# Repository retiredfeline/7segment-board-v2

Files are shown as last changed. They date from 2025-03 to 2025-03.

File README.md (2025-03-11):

# 7 segment 2 digit board

These are the design files for a 7 segment board similar to [6 segment 2 digit board](https://hackaday.io/project/175397-6-segment-2-digit-led-board).

This is a multiplexed design with 7 cathode segment drive lines plus 1 colon line. The cathode drive lines are taken low to turn on the LEDs, while the anode drive lines are taken low to turn on the transistors.

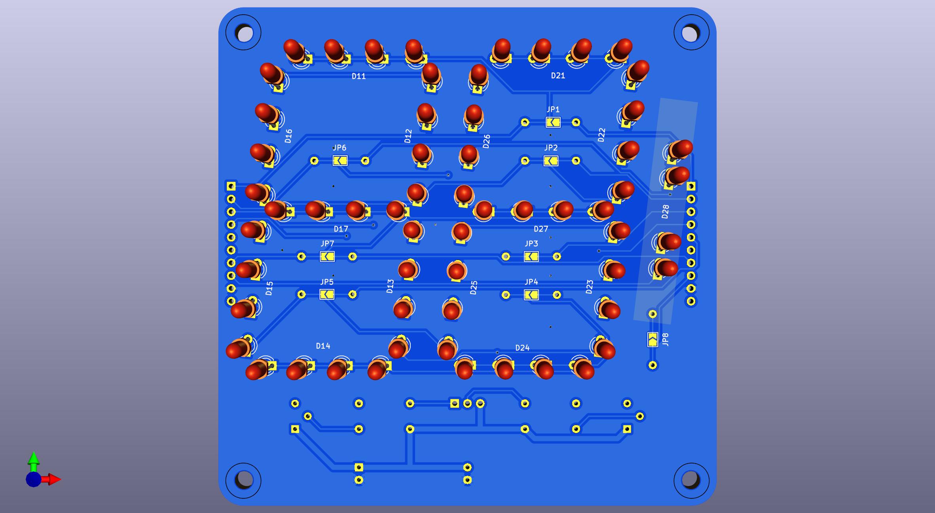
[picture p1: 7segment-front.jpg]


## Versioning

Release March 2025

## Notes

Most components are installed on the back side and the LEDs are installed on the front side.

The PNP transistors need a gain > 40. A bit more margin is recommended.

Note the the LED supply voltage will need to be higher than 4x the LED drop and the cathode current limiting resistor should be calculated accordingly. So 5V will not be sufficient and also a buffer stage will be needed for most MCUs. For example with a 12V supply and green (not emerald) LEDs, the voltage drop per LED is 2V. The transistor drops will be around 0.8V. That leaves 2.2V to be dropped across the resistor. A 220Ω resistor gives 10mA through the LED. For 4 digits multiplexed this is effectively 2.5mA. Modern LEDs are efficient enough to shine brightly at such currents. For dimming, use PWM.

When cascading only the rightmost board needs to be fully populated. The others need only the LEDs, the anode driver transistors, and its resistors. The cathode resistors are not installed and the solder jumpers are closed.

## Authors

* **Ken Yap**

## License

See the [LICENSE](LICENSE.md) file for license rights and limitations (MIT).

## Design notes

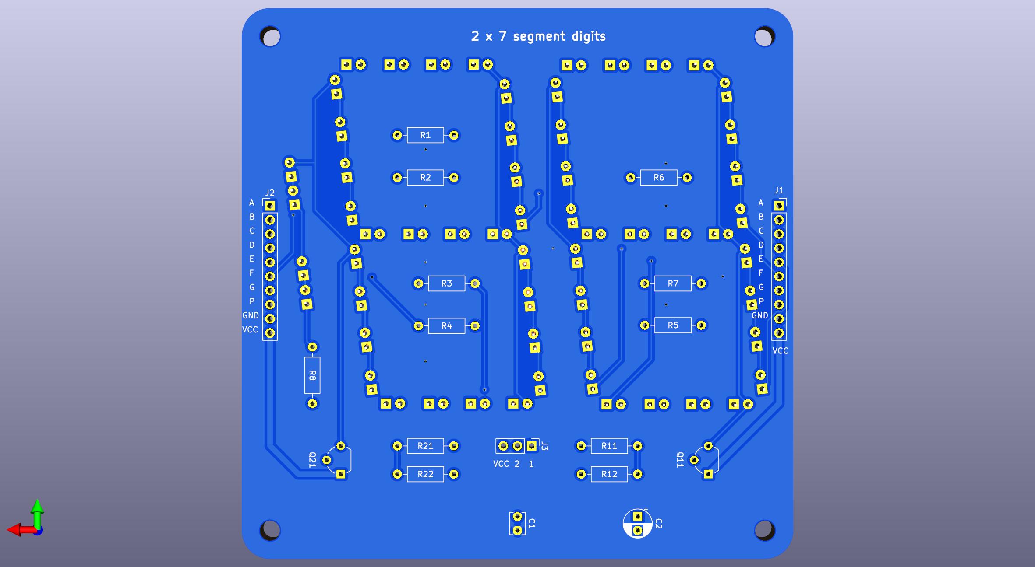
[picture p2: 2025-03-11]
7segment-back.jpg

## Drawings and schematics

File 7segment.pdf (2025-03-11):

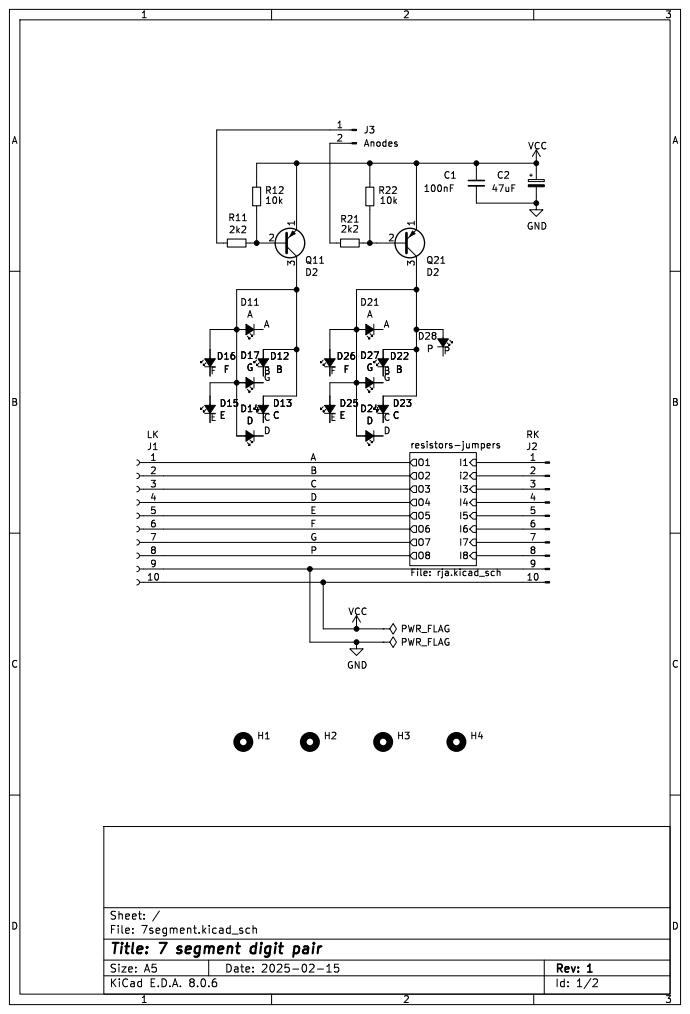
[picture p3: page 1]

Id: 1/2 Title: 7 segment digit pair File: 7segment.kicad_sch Sheet: /

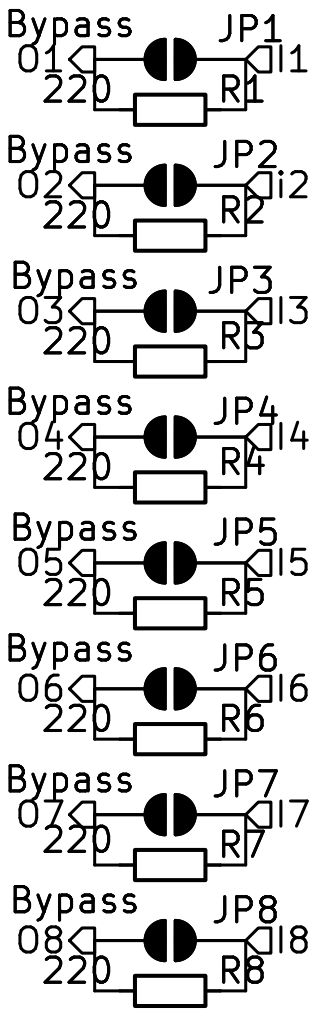
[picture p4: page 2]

File: rja.kicad_sch Sheet: /resistors-jumpers/
Id: 2/2 Title: Resistor jumper array

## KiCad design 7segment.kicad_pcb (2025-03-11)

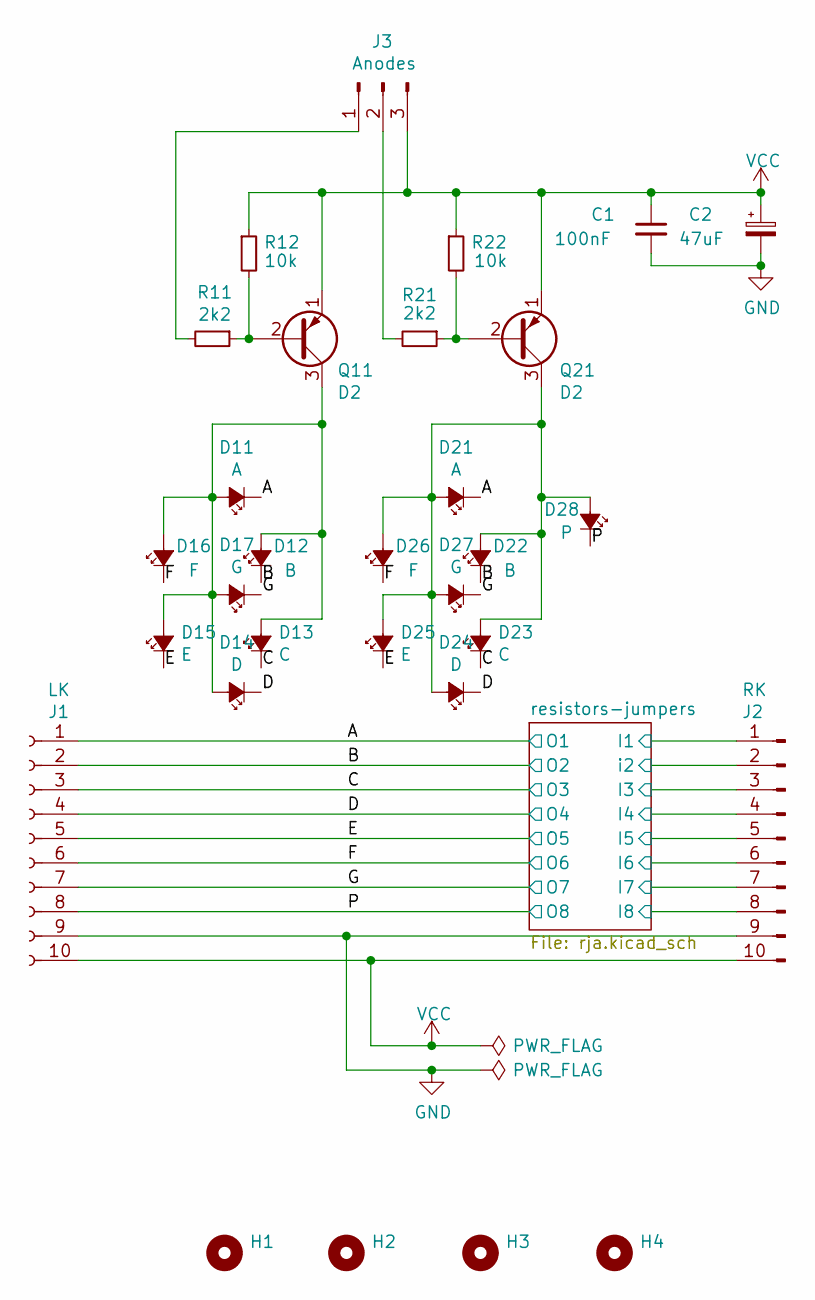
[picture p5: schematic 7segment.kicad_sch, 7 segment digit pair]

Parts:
C1: 100nF; C_Disc_D3.8mm_W2.6mm_P2.50mm
C2: 47uF; CP_Radial_D5.0mm_P2.50mm
D11, D21: A; LED_D3.0mmx4
D12, D22: B; LED_D3.0mmx4
D13, D23: C; LED_D3.0mmx4
D14, D24: D; LED_D3.0mmx4
D15, D25: E; LED_D3.0mmx4
D16, D26: F; LED_D3.0mmx4
D17, D27: G; LED_D3.0mmx4
D28: P; LED_D3.0mm-colon
H1, H2, H3, H4: MountingHole; MountingHole_3.5mm
J1: LK; PinSocket_1x10_P2.54mm_Vertical
J2: RK; PinHeader_1x10_P2.54mm_Vertical
J3: Anodes; PinHeader_1x03_P2.54mm_Vertical
Q11, Q21: D2; TO-92_Wide
R11, R21: 2k2; R_Axial_DIN0207_L6.3mm_D2.5mm_P10.16mm_Horizontal
R12, R22: 10k; R_Axial_DIN0207_L6.3mm_D2.5mm_P10.16mm_Horizontal

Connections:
/A: D11.1 (K), D21.1 (K), J1.1; also elsewhere on the board
/B: D12.1 (K), D22.1 (K), J1.2; also elsewhere on the board
/C: D13.1 (K), D23.1 (K), J1.3; also elsewhere on the board
/D: D14.1 (K), D24.1 (K), J1.4; also elsewhere on the board
/E: D15.1 (K), D25.1 (K), J1.5; also elsewhere on the board
/F: D16.1 (K), D26.1 (K), J1.6; also elsewhere on the board
/G: D17.1 (K), D27.1 (K), J1.7; also elsewhere on the board
/P: D28.1 (K), J1.8; also elsewhere on the board
/resistors-jumpers/I1: J2.1; also elsewhere on the board
/resistors-jumpers/I3: J2.3; also elsewhere on the board
/resistors-jumpers/I4: J2.4; also elsewhere on the board
/resistors-jumpers/I5: J2.5; also elsewhere on the board
/resistors-jumpers/I6: J2.6; also elsewhere on the board
/resistors-jumpers/I7: J2.7; also elsewhere on the board
/resistors-jumpers/I8: J2.8; also elsewhere on the board
/resistors-jumpers/i2: J2.2; also elsewhere on the board
GND: C1.2, C2.2, J1.9, J2.9
unnamed: D11.2 (A), D12.2 (A), D13.2 (A), D14.2 (A), D15.2 (A), D16.2 (A), D17.2 (A), Q11.3 (C)
unnamed: D21.2 (A), D22.2 (A), D23.2 (A), D24.2 (A), D25.2 (A), D26.2 (A), D27.2 (A), D28.2 (A), Q21.3 (C)
unnamed: J3.1, R11.2
unnamed: J3.2, R21.2
unnamed: Q11.2 (B), R11.1, R12.2
unnamed: Q21.2 (B), R21.1, R22.2
VCC: C1.1, C2.1, J1.10, J2.10, J3.3, Q11.1 (E), Q21.1 (E), R12.1, R22.1

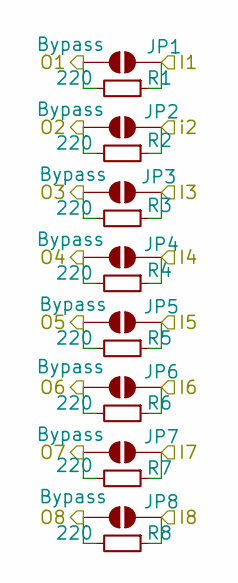
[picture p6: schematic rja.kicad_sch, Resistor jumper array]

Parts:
JP1, JP2, JP3, JP4, JP5, JP6, JP7, JP8: Bypass; SolderJumper-2_P1.3mm_Open_TrianglePad1.0x1.5mm
R1, R2, R3, R4, R5, R6, R7, R8: 220; R_Axial_DIN0207_L6.3mm_D2.5mm_P10.16mm_Horizontal

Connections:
/A: JP1.2 (B), R1.2; also elsewhere on the board
/B: JP2.2 (B), R2.2; also elsewhere on the board
/C: JP3.2 (B), R3.2; also elsewhere on the board
/D: JP4.2 (B), R4.2; also elsewhere on the board
/E: JP5.2 (B), R5.2; also elsewhere on the board
/F: JP6.2 (B), R6.2; also elsewhere on the board
/G: JP7.2 (B), R7.2; also elsewhere on the board
/P: JP8.2 (B), R8.2; also elsewhere on the board
/resistors-jumpers/I1: JP1.1 (A), R1.1; also elsewhere on the board
/resistors-jumpers/I3: JP3.1 (A), R3.1; also elsewhere on the board
/resistors-jumpers/I4: JP4.1 (A), R4.1; also elsewhere on the board
/resistors-jumpers/I5: JP5.1 (A), R5.1; also elsewhere on the board
/resistors-jumpers/I6: JP6.1 (A), R6.1; also elsewhere on the board
/resistors-jumpers/I7: JP7.1 (A), R7.1; also elsewhere on the board
/resistors-jumpers/I8: JP8.1 (A), R8.1; also elsewhere on the board
/resistors-jumpers/i2: JP2.1 (A), R2.1; also elsewhere on the board

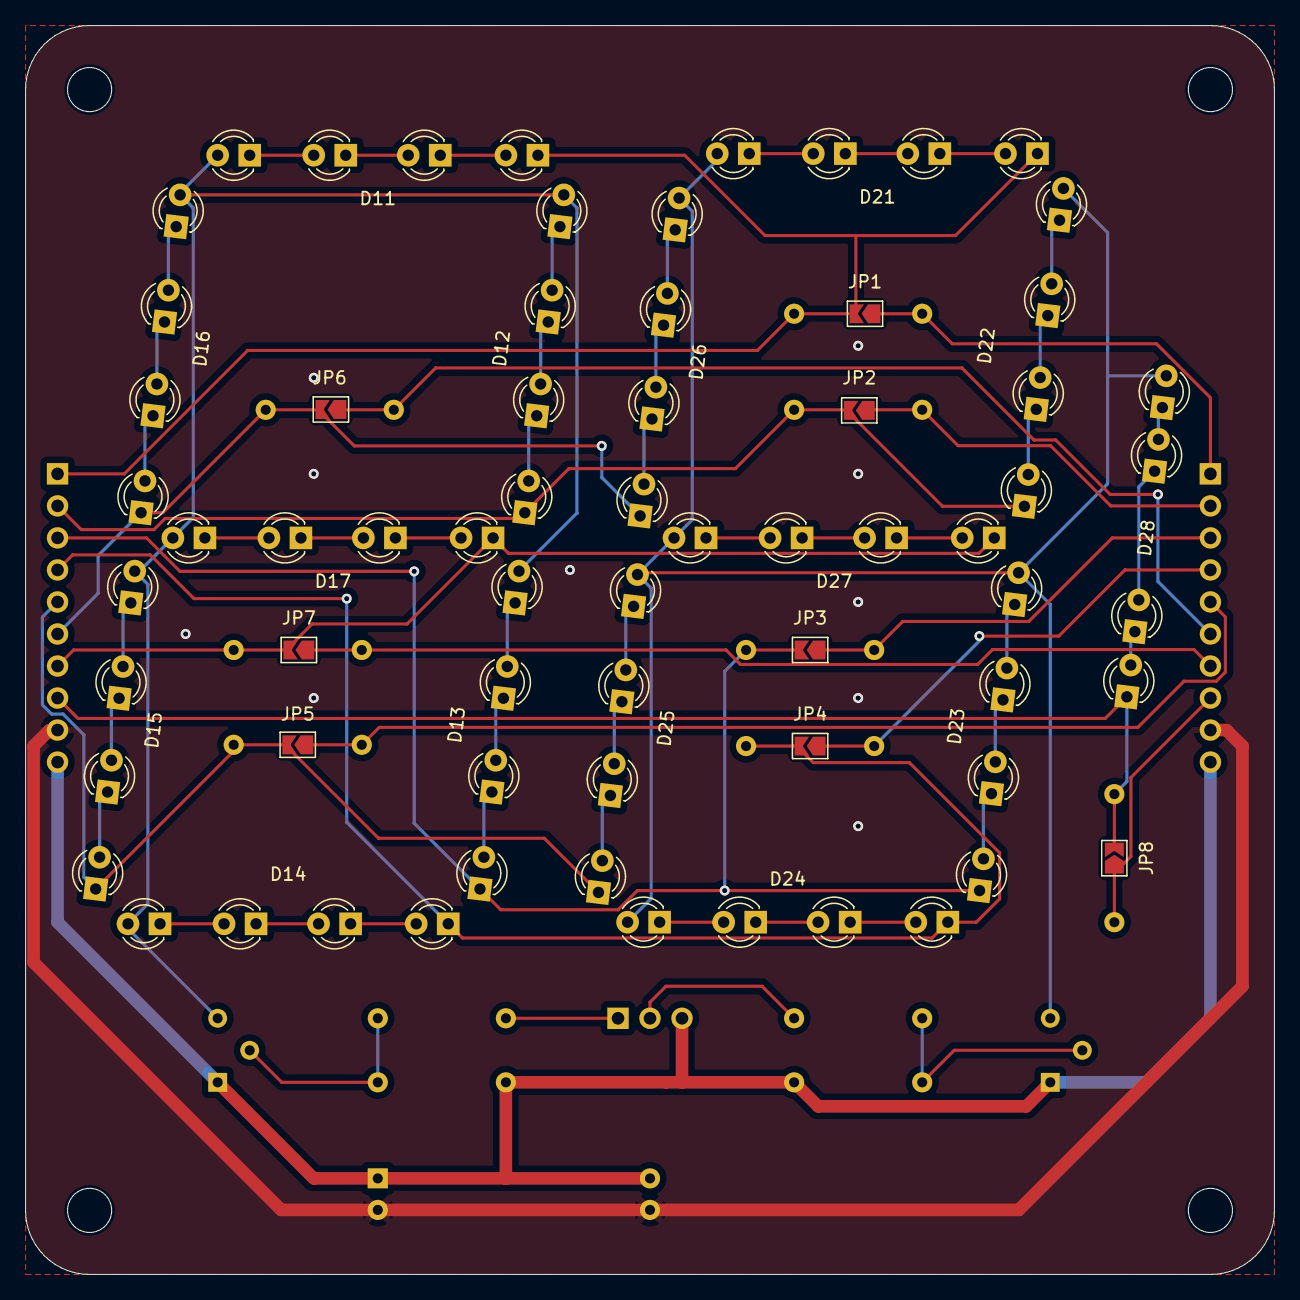
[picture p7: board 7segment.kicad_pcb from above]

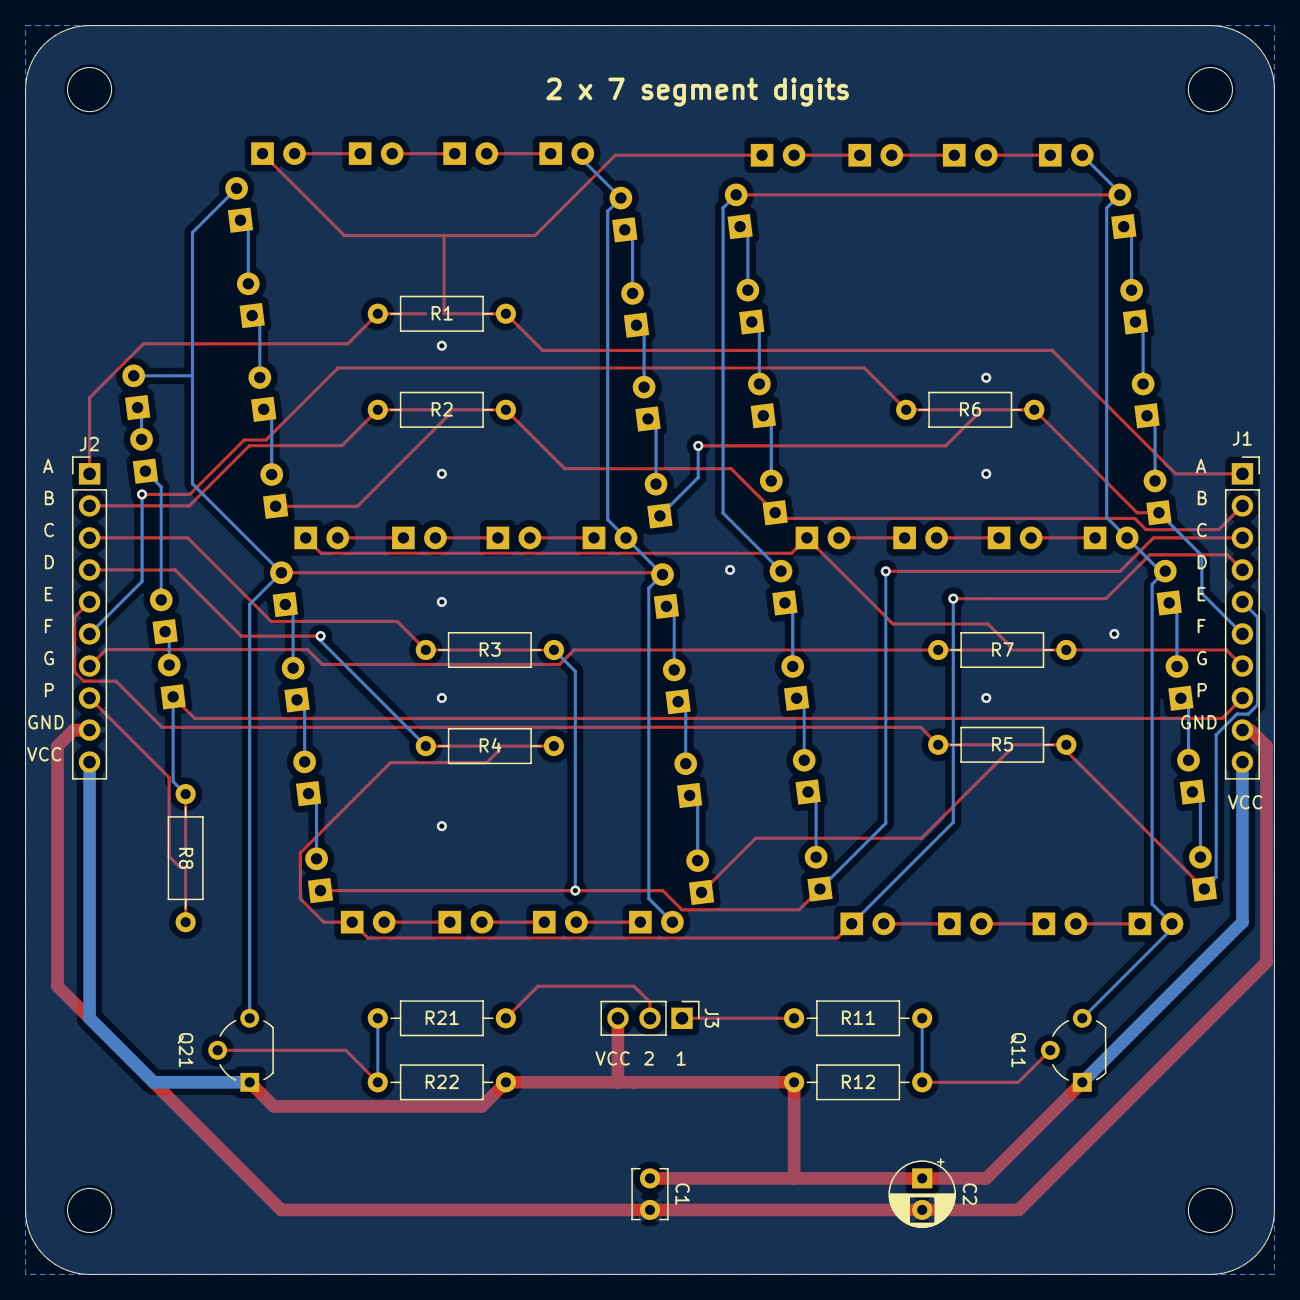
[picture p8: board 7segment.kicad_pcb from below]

Board: 2 copper layers, 99.1 x 99.1 mm, 46 parts (19 on the bottom side), 24 nets.
